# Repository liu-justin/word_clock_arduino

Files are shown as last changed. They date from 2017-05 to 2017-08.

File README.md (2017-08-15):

# word_clock_arduino
Building a word clock powered by an arduino.

In this project, I took inspiration from various online guides on how to make a word clock, particularly from this link
http://imgur.com/a/iMXmj

The way my word clock is different is the size (11x11) and the fact that all lights are controlled individually, instead of chaining lights together by word. By doing this, I increase the programability of the clock, meaning I can switch out different templates and change the code and the clock will change to the new clock.

The main guts of the clock come in the form of shift registers. Due the low amount of IO pins on a standard Arduino, a shift register allows 8 outputs for only 3 inputs. They can be put in series to allow for potentially infinite outputs. If you don't know how shift registers work, I learned from this video.

https://www.youtube.com/watch?v=6fVbJbNPrEU

It really doesn't matter which kind of shift register you use, you just have to understand which pins do what. For example, I used the 74hc595, and the pins can be found in this image: https://cdn.instructables.com/FHH/ICV1/H5TUC8B2/FHHICV1H5TUC8B2.MEDIUM.jpg . Looking at it, Pin 9 is labeled as Serial Out, which means that to chain shift registers A and B together, you need to connect Pin 9 (serial out) of A to Pin 3 (serial data in) of B. If you are having trouble, look for a guide online, such as this one:

https://www.arduino.cc/en/Tutorial/ShiftOut

In order to control all 121 lights individually, I took the long route by daisychaining 16 shift registers together. In the first posted link, the user had used 3 shift registers to control about 20-30 words. Other clocks, such as the one in this link,

http://imgur.com/a/dtLSy

used individually addressed LEDs, which have shift registers built into them. In hindsight, I would have preferred to use these individually addressable LEDs, but the journey was fun and exciting to jump into as a dip into the world of electrical engineering. Also, I have a word clock that I can proudly label as my own invention, with my own spin onto it.

The general layout of the design:
- Arduino provides power, ground, and the 3 IO pins needed to operate a shift register/chain of shift registers
- 16 shift registers are placed on a PCB, which was designed so that the end of each shift register leads to the beginning of another
- each shift register controls 8 LEDs, with the last shift register only controlling one LED (121%8 = 1)
- all LEDs are grounded

Because the shift registers can only have 8 outputs, and my grid is 11x11, the spacing of the LEDS is up to discretion. I tried to make it in rows for ease of programability, as shown in the excel file. I am absolutely positive that there is a better way of spacing them, but this setup works for me.

To light up the LEDs, I needed to send 16 bytes of data to the 16 shift registers, which each have 8 binary outputs (otherwise known as a byte). The first byte is sent to the last shift register, and the last byte is sent to the first shift register. To know which byte to send, look at the bottom right grid in my excel sheet titled lettering. The reading is from left to right, top to bottom. Just pick the words you want to light up, and convert the binary to decimal.

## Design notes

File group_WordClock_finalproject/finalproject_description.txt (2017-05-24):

In this final project, I designed, built, and wired a word clock powered by an Arduino. I have also linked a GUI to processing for settting the time. Currently, it requires the user to plug in the USB cable into a computer to set the time, and to plug in a 9V power adapter. Once the time has been set, the USB can be disconnected and the clock will run as it should.

As for the actual guts of the machine, the Arduino powers 16 shift registers, which each control 8 LEDS (except for the last one, which only powers 1). There are 121 LEDS that can each be controlled individually, meaning that if I wanted to change the lettering board, I would only have to change the code itself and not do any extra wiring.

One of the major unexpected problems was the whole entire process. I redesigned the wiring many times, switching from LED strips to word-linked LEDS to individually linked LEDS. I failed about 8 times to print my circuit board, and the wiring was too long so I had to ziptie the size down.

All in all, this was a very fun and rewarding project, and I plan to make improvements upon it in the future. Perhaps adding physical buttons to change the time so the USB is no longer needed, or making the box thinner.

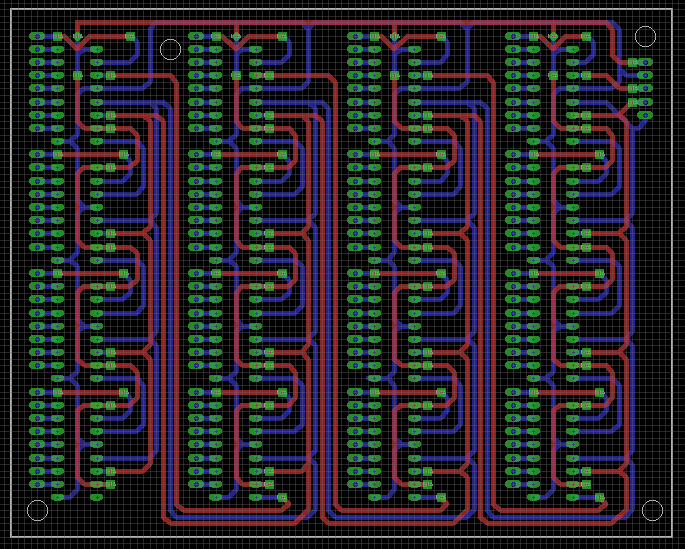
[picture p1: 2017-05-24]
PCB.png

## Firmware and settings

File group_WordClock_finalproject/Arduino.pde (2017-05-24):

//int datapin = 2; 
//int clockpin = 3;
//int latchpin = 4;
//byte data = 0;

//void setup()
//{
//  pinMode(datapin, OUTPUT);
//  pinMode(clockpin, OUTPUT);  
//  pinMode(latchpin, OUTPUT);

//  Serial.begin(9600);
//}

//byte lightArray[16][9] = {
//  {30,0,0,0,0,0,0,0,0} , // 0
//  {224,15,0,0,0,0,0,0,0} , // 1
//  {240,7,0,0,0,0,0,0,0} , // 2
//  {60,0,0,0,0,0,0,0,0} , // 3
//  {7,0,0,0,0,0,0,0,0} , // 4
//  {112,7,0,0,0,0,0,0,0} , // 5
//  {60,1,0,0,0,0,0,0,0} , // 6
//  {112,7,0,0,0,0,0,0,0} , // 7
//  {248,1,0,0,0,0,0,0,0} , // 8
//  {124,7,0,0,0,0,0,0,0} , // 9
//  {252,1,0,0,0,0,0,0,0} , // 10
//  {128,64,32,16,8,4,2,1,0} , // 11
//  {128,64,32,16,8,4,2,1,0} , // 12
//  {128,64,32,16,8,4,2,1,0} , // 13
//  {192,28,3,0,0,0,0,0,0} , // 14
//  {1,0,0,0,0,0,0,0,0} , // 15
//  };

//byte lightIndex[16] = {0,0,0,0,0,0,0,0,0,0,0,0,0,0,0,0};

//void reset()
//{
//  for (int i = 0; i  < 16; i++)
//  {
//    lightIndex[i] = 0;
//  }
//}

//void convert(int val_)
//{
//  reset();
//  boolean inHour;
//  if (val_%100 <= 30) {inHour = true;}
//  else { inHour = false;}

//  lightIndex[11] = lightArray[11][0];
//  lightIndex[12] = lightArray[12][0];
//  lightIndex[13] = lightArray[13][0];
  
//  if ((val_/100 == 1 && inHour) || (val_/100 == 12 && !inHour)) // ONE
//  {
//    lightIndex[14] += lightArray[14][1];
//  }
//  else if ((val_/100 == 2 && inHour) || (val_/100 == 1 && !inHour)) // TWO
//  {
//    lightIndex[7] += lightArray[7][0];
//  }
//  else if ((val_/100 == 3 && inHour) || (val_/100 == 2 && !inHour)) // THREE
//  {
//    lightIndex[9] += lightArray[9][0];
//  }
//  else if ((val_/100 == 4 && inHour) || (val_/100 == 3 && !inHour)) // FOUR
//  {
//    lightIndex[10] += lightArray[10][1];
//    lightIndex[14] += lightArray[14][2];
//    lightIndex[15] += lightArray[15][0];
//  }
//  else if ((val_/100 == 5 && inHour) || (val_/100 == 4 && !inHour)) // FIVE
//  {
//    lightIndex[11] += lightArray[11][6];
//    lightIndex[12] += lightArray[12][6];
//    lightIndex[13] += lightArray[13][6];
//    lightIndex[6] += lightArray[6][1];
//  }
//  else if ((val_/100 == 6 && inHour) || (val_/100 == 5 && !inHour)) // SIX
//  {
//    lightIndex[14] += lightArray[14][0];
//    lightIndex[8] += lightArray[8][1];
//  }
//  else if ((val_/100 == 7 && inHour) || (val_/100 == 6 && !inHour)) // SEVEN
//  {
//    lightIndex[4] += lightArray[4][0];
//    lightIndex[11] += lightArray[11][4];
//    lightIndex[12] += lightArray[12][4];
//  }
//  else if ((val_/100 == 8 && inHour) || (val_/100 == 7 && !inHour)) // EIGHT
//  {
//    lightIndex[8] += lightArray[8][0];
//  }
//  else if ((val_/100 == 9 && inHour) || (val_/100 == 8 && !inHour)) // NINE
//  {
//    lightIndex[6] += lightArray[6][0];
//  }
//  else if ((val_/100 == 10 && inHour) || (val_/100 == 9 && !inHour)) // TEN
//  {
//    lightIndex[5] += lightArray[5][0];
//  }
//  else if ((val_/100 == 11 && inHour) || (val_/100 == 10 && !inHour)) // ELEVEN
//  {
//    lightIndex[7] += lightArray[7][1];
//    lightIndex[11] += lightArray[11][7];
//    lightIndex[12] += lightArray[12][7];
//    lightIndex[13] += lightArray[13][7];
//  }
//  else if ((val_/100 == 12 && inHour) || (val_/100 == 11 && !inHour)) // TWELVE
//  {
//    lightIndex[5] += lightArray[5][1];
//    lightIndex[11] += lightArray[11][5];
//    lightIndex[12] += lightArray[12][5];
//    lightIndex[13] += lightArray[13][5];
//  }

//  if (val_%100 == 0) // OCLOCK
//  {
//    lightIndex[10] += lightArray[10][0];
//  }
//  else if (val_%100 == 5) // FIVE PAST
//  {
//    lightIndex[2] += lightArray[2][0];
//    lightIndex[3] += lightArray[3][0];
//  }
//  else if (val_%100 == 10) // TEN PAST
//  {
//    lightIndex[1] += lightArray[1][0];
//    lightIndex[3] += lightArray[3][0];
//  }
//  else if (val_%100 == 15) // QUARTER PAST
//  {
//    lightIndex[1] += lightArray[1][1];
//    lightIndex[3] += lightArray[3][0];  
//    lightIndex[11] += lightArray[11][1];
//    lightIndex[12] += lightArray[12][1];
//    lightIndex[13] += lightArray[13][1];
//  }
//  else if (val_%100 == 20) // TWENTY PAST
//  {
//    lightIndex[2] += lightArray[2][1];
//    lightIndex[3] += lightArray[3][0];
//    lightIndex[11] += lightArray[11][2];
//    lightIndex[12] += lightArray[12][2];
//    lightIndex[13] += lightArray[13][2];
//  }
//  else if (val_%100 == 25) // TWENTY FIVE PAST
//  {
//    lightIndex[2] += lightArray[2][0];
//    lightIndex[2] += lightArray[2][1];
//    lightIndex[3] += lightArray[3][0];
//    lightIndex[11] += lightArray[11][2];
//    lightIndex[12] += lightArray[12][2];
//    lightIndex[13] += lightArray[13][2];
    
//  }
//  else if (val_%100 == 30) // HALF PAST
//  {
//    lightIndex[0] += lightArray[0][0];
//    lightIndex[3] += lightArray[3][0];
//  }
//  else if (val_%100 == 35) // TWENTY FIVE TIL
//  {
//    lightIndex[2] += lightArray[2][0];
//    lightIndex[2] += lightArray[2][1];
//    lightIndex[11] += lightArray[11][2];
//    lightIndex[12] += lightArray[12][2];
//    lightIndex[13] += lightArray[13][2];
//    lightIndex[11] += lightArray[11][3];
//    lightIndex[12] += lightArray[12][3];
//    lightIndex[13] += lightArray[13][3];
//  }
//  else if (val_%100 == 40) // TWENTY TIL
//  {
//    lightIndex[2] += lightArray[2][1];
//    lightIndex[11] += lightArray[11][2];
//    lightIndex[12] += lightArray[12][2];
//    lightIndex[13] += lightArray[13][2];
//    lightIndex[11] += lightArray[11][3];
//    lightIndex[12] += lightArray[12][3];
//    lightIndex[13] += lightArray[13][3];
//  }
//  else if (val_%100 == 45) // QUARTER TIL
//  {
//    lightIndex[1] += lightArray[1][1]; 
//    lightIndex[11] += lightArray[11][1];
//    lightIndex[12] += lightArray[12][1];
//    lightIndex[13] += lightArray[13][1];
//    lightIndex[11] += lightArray[11][3];
//    lightIndex[12] += lightArray[12][3];
//    lightIndex[13] += lightArray[13][3];
//  }
//  else if (val_%100 == 50) // TEN TIL
//  {
//    lightIndex[1] += lightArray[1][0];
//    lightIndex[11] += lightArray[11][3];
//    lightIndex[12] += lightArray[12][3];
//    lightIndex[13] += lightArray[13][3];
//  }
//  else if (val_%100 == 55) // FIVE TIL
//  {
//    lightIndex[2] += lightArray[2][0];
//    lightIndex[11] += lightArray[11][3];
//    lightIndex[12] += lightArray[12][3];
//    lightIndex[13] += lightArray[13][3];
//  }

//}

//int lightArrays[16]= {255,0,0,0,0,0,0,0,0,0,0,0,0,0,0,0};

//void checking()
//{
//  int delayTime = 10;
//  for (int i = 15; i >= 0; i--)
//  {
//    shiftOut(datapin, clockpin, MSBFIRST, lightIndex[i]);
//  }
  
//  digitalWrite(latchpin, HIGH);
//  digitalWrite(latchpin, LOW);

//  delay(delayTime);
//}

//void test()
//{
//  int delayTime = 10;

//  for (int i = 15; i >= 0; i--)
//  {
//    shiftOut(datapin, clockpin, MSBFIRST, lightIndex[i]);
//  }

//  digitalWrite(latchpin, HIGH);
//  digitalWrite(latchpin, LOW);

//  delay(delayTime);  
//}

//long currentTime = 0;
//long waitTime = 300000;
//int code = 0;
//int val = 100;

//void loop()
//{
//  if (Serial.available())
//  {
//    code = Serial.read();
//    val = 100 + 100*(code/12) + 5*(code%12);
//    currentTime = millis();
//  }
  
//  convert(val);
//  test();
//  if ((millis() - currentTime) >= waitTime)
//  {
//    code = code + 1;
//    if (code == 144) { code = 0;}
//    val = 100 + 100*(code/12) + 5*(code%12);
//    currentTime = millis();
//  }

//  //checking();
//}

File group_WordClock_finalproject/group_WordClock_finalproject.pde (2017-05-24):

// NOTE: I HAVE COMMENTED OUT SOME PORTIONS OF THE CODE THAT REQUIRE THE USB
//       TO BE PLUGGED IN, BECAUSE THE PROGRAM WILL NOT RUN IF THESE LINES OF
//       CODE ARE PROCESSED AND THERE IS NO CONNECTION IN THE USB

// NOTE: THE ARDUINO CODE IS IN THE TAB LABELED ARDUINO, ALL COMMENTED

import processing.serial.*;

Serial myPort;

radioButtonSet hours;
radioButtonSet minutes;

void setup()
{
  size(500,500);
  
  // COMMENTED OUT FOR GRADING
  
  //String portName = Serial.list()[0];
  //myPort = new Serial(this, portName, 9600);
  
  // COMMENTED OUT FOR GRADING
  
  textSize(25);
  background(100);
  text("Enter the time: ", 150,100);
  
  // initialize the radio buttons
  hours = new radioButtonSet(12,10,200,1,0);
  minutes = new radioButtonSet(12,10,300,5,1);
  
  // display the radio buttons
  hours.displayButtons();
  minutes.displayButtons();
}

// This is converted and sent to the Arduino
String value = "";

void keyPressed()
{
  background(100);
  hours.displayButtons();
  minutes.displayButtons();
  text("Enter the time: ", 150,100);

  // If enter is pressed and the time is valid, send it to the Arduino
  if (keyCode == ENTER && value.length() >= 3)
  {
    // convert value to int
    int numberValue = Integer.parseInt(value);
    // convert value into a number less than 255;
    int code = convert(numberValue);
    int lastDigit = Integer.parseInt(value.substring(value.length()-1, value.length()));
    // COMMENTED OUT FOR GRADING
    
    //myPort.write(code);
    
    // COMMENTED OUT FOR GRADING
  }
}

void mousePressed()
{
  for (int i = 0; i < hours.power.length; i++)
  {
    if (hours.hoverCheck(hours.startX + 25*i, hours.startY) == true)
    {
      hours.switchFeeds(i);
    }
  }
  for (int j = 0; j < minutes.power.length; j++)
  {
    if (minutes.hoverCheck(minutes.startX + 25*j, minutes.startY) == true)
    {
      minutes.switchFeeds(j);
    }
  }
}

// for some reason, i can only send ints less than 255 to the Arduino
// so I convert the value, 100 --> 0, 105 --> 1 and so on
int convert(int value_)
{
  // algorithm to convert to values less than 255
  int code = (value_%100/5)+12*(value_/100-1);
  println(code);
  return code;
}



void draw()
{
  background(100);
  hours.displayButtons();
  minutes.displayButtons();
  text("Enter the time: ", 150,100);
  text("Press Enter to set the time.",75,400);
  if ((minutes.current+1)*5 == 5 || (minutes.current+1)*5 == 10)
  {
    value = str(hours.current+1) + "0" + str((minutes.current)*5);
    textSize(50);
    text(str(hours.current+1) + ":0" + str((minutes.current)*5),335,270);
    textSize(25);
  }
  else
  {
    value = str(hours.current+1) + str((minutes.current)*5);
    textSize(50);
    text(str(hours.current+1) + ":" + str((minutes.current)*5),335,270);
    textSize(25);
  }

  
}
